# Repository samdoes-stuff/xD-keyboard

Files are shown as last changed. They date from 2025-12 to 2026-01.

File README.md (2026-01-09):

# xD-keyboard
xD keyboard is nRF52 based wireless mechanical keyboard equipped with Gateron KS-33 low profile key switches. 

# PCB 

Generated with KLEPCBGEN. Designed with both Kicad & Easyeda PRO.

Screenshot 2026-01-08 231322 - Copy













# Case & Plate 

Generated with Swillkb & Keebio. Designed with Fusion 360. Chopped with Bamboo lab Studio.





Counter sink screw holes







# Bootloader & Firmware

Bootloader generated from Adafruit_nRF52_Bootloader & Firmware made with ZMK with Custom Board.
- ZMK Ultra-Low-Power Mode
- Deep sleep between keypresses
- BLE connection optimization
- Soft-off / idle timeout
- ZMK USB HID (wired mode)

#BOM 

Refer to BOM.csv

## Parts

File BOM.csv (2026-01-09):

Index | LCSC# | MPN | Manufacturer | Package |  |  | Quantity | MOQ | Unit Price($) | Extended Price($) | Product Link
1 | C23733 | CL05A475MP5NRNC | Samsung Electro-Mechanics | 402 |  |  | 50 | 50 | 0.0049 | 0.25 | https://www.lcsc.com/product-detail/C23733.html
2 | C52923 | CL05A105KA5NQNC | Samsung Electro-Mechanics | 402 |  |  | 100 | 100 | 0.003 | 0.3 | https://www.lcsc.com/product-detail/C52923.html
3 | C272875 | CC0402KRX7R9BB473 | YAGEO | 402 |  |  | 100 | 100 | 0.0024 | 0.24 | https://www.lcsc.com/product-detail/C272875.html
4 | C1523 | 0402B102K500NT | FH | 402 |  |  | 100 | 100 | 0.0011 | 0.11 | https://www.lcsc.com/product-detail/C1523.html
5 | C1546 | 0402CG101J500NT | FH | 402 |  |  | 100 | 100 | 0.001 | 0.1 | https://www.lcsc.com/product-detail/C1546.html
6 | C307331 | CL05B104KB54PNC | Samsung Electro-Mechanics | 402 |  |  | 100 | 100 | 0.0038 | 0.38 | https://www.lcsc.com/product-detail/C307331.html
7 | C1548 | 0402CG150J500NT | FH | 402 |  |  | 100 | 100 | 0.001 | 0.1 | https://www.lcsc.com/product-detail/C1548.html
8 | C1552 | 0402CG1R5C500NT | FH | 402 |  |  | 100 | 100 | 0.0012 | 0.12 | https://www.lcsc.com/product-detail/C1552.html
9 | C1550 | 0402CG1R0C500NT | FH | 402 |  |  | 100 | 100 | 0.0012 | 0.12 | https://www.lcsc.com/product-detail/C1550.html
10 | C15195 | CL05B103KB5NNNC | Samsung Electro-Mechanics | 402 |  |  | 100 | 100 | 0.0013 | 0.13 | https://www.lcsc.com/product-detail/C15195.html
11 | C72038 | 19-213/Y2C-CQ2R2L/3T(CY) | EVERLIGHT | 603 |  |  | 30 | 30 | 0.0208 | 0.62 | https://www.lcsc.com/product-detail/C72038.html
12 | C8598 | B5819W SL | JSCJ | SOD-123 |  |  | 20 | 20 | 0.023 | 0.46 | https://www.lcsc.com/product-detail/C8598.html
13 | C2290 | KT-0603W | Hubei KENTO Elec | 603 |  |  | 50 | 50 | 0.0106 | 0.53 | https://www.lcsc.com/product-detail/C2290.html
14 | C7420320 | 1N4148WT | R+O | SOD-523 |  |  | 100 | 50 | 0.0111 | 1.11 | https://www.lcsc.com/product-detail/C7420320.html
15 | C76763 | MLG1005S15NJT000 | TDK | 402 |  |  | 10 | 10 | 0.0064 | 0.06 | https://www.lcsc.com/product-detail/C76763.html
16 | C76732 | MLF1608E100KTD00 | TDK | 603 |  |  | 10 | 10 | 0.0417 | 0.42 | https://www.lcsc.com/product-detail/C76732.html
17 | C76775 | MLG1005S3N9BT000 | TDK | 402 |  |  | 10 | 10 | 0.0083 | 0.08 | https://www.lcsc.com/product-detail/C76775.html
18 | C165948 | TYPE-C-31-M-12 | Korean Hroparts Elec | SMD |  |  | 5 | 5 | 0.1762 | 0.88 | https://www.lcsc.com/product-detail/C165948.html
19 | C17168 | 0402WGF0000TCE | UNI-ROYAL | 402 |  |  | 100 | 100 | 0.0006 | 0.06 | https://www.lcsc.com/product-detail/C17168.html
20 | C25744 | 0402WGF1002TCE | UNI-ROYAL | 402 |  |  | 100 | 100 | 0.0006 | 0.06 | https://www.lcsc.com/product-detail/C25744.html
21 | C13167 | 0603WAF2701T5E | UNI-ROYAL | 603 |  |  | 100 | 100 | 0.0012 | 0.12 | https://www.lcsc.com/product-detail/C13167.html
22 | C25867 | 0402WGF1501TCE | UNI-ROYAL | 402 |  |  | 100 | 100 | 0.0006 | 0.06 | https://www.lcsc.com/product-detail/C25867.html
23 | C25905 | 0402WGF5101TCE | UNI-ROYAL | 402 |  |  | 100 | 100 | 0.0006 | 0.06 | https://www.lcsc.com/product-detail/C25905.html
24 | C22976 | 0603WAF2004T5E | UNI-ROYAL | 603 |  |  | 100 | 100 | 0.0013 | 0.13 | https://www.lcsc.com/product-detail/C22976.html
25 | C26082 | 0402WGF1005TCE | UNI-ROYAL | 402 |  |  | 100 | 100 | 0.0006 | 0.06 | https://www.lcsc.com/product-detail/C26082.html
26 | C26083 | 0402WGF1004TCE | UNI-ROYAL | 402 |  |  | 100 | 100 | 0.0006 | 0.06 | https://www.lcsc.com/product-detail/C26083.html
27 | C318884 | TS-1187A-B-A-B | XKB Connection | SMD-4P,5.1x5.1mm |  |  | 20 | 20 | 0.0195 | 0.39 | https://www.lcsc.com/product-detail/C318884.html
28 | C202311 | BQ21040DBVR | TI | SOT-23-6 |  |  | 5 | 5 | 0.2758 | 1.38 | https://www.lcsc.com/product-detail/C202311.html
29 | C190794 | NRF52840-QIAA-R | NORDIC | AQFN-73-EP(7x7) |  |  | 1 | 1 | 4.5064 | 4.51 | https://www.lcsc.com/product-detail/C190794.html
30 | C94372 | ESDR0502NMUTAG | onsemi | UDFN-6(1x1.2) |  |  | 5 | 5 | 0.2563 | 1.28 | https://www.lcsc.com/product-detail/C94372.html
31 | C99009 | X1A0000610006 | EPSON | SMD2012-2P |  |  | 5 | 5 | 0.2058 | 1.03 | https://www.lcsc.com/product-detail/C99009.html
32 | C2965584 | XL7EL89COI-111YLC-32M | YXC Crystal Oscillators | SMD2016-4P |  |  | 10 | 10 | 0.0747 | 0.75 | https://www.lcsc.com/product-detail/C2965584.html
33 |  | Raspberry pi pico or xiao rp2040 for booting the MCU |  |  |  |  | 1 | 1 | 0 | 0 | I have ONE
34 | C42393296 |  | Single Conductor HookUp Wire |  |  |  | 4 | 50 | $0.01 | $0.48 | https://www.lcsc.com/product-detail/C42393296.html
35 |  | Gateron Low Profile Switch (Brown) |  |  |  |  | 60 | 70 | 21.65 | 21.65 | https://www.aliexpress.com/item/1005006870413847.html?mp=1
36 |  | Low Profile Keycaps |  |  |  |  | 60 | 60 | 17.81 | 17.81 | https://www.aliexpress.com/item/1005007750036083.html?mp=1
37 |  | Hot Swap Sockets |  |  |  |  | 60 | 70 | 8.53 | 8.53 | https://www.aliexpress.com/item/1005007267551458.html?mp=1
38 |  | Low Profile Stabilizer Set |  |  |  |  | set of 5 | set of 5 | 11.59 | 11.59 | https://www.aliexpress.com/item/1005005296240590.html?mp=1
39 |  | Keyboard PCB (ENIG for nRF52 bga) |  |  |  |  |  |  | 58.6 | 58.6
40 |  | JLCPCB SHIPPING |  |  |  |  |  |  | 14.85 | 14.85
41 |  | LCSC SHIPPING |  | SINGAPORE POST |  |  |  |  | 13.29 | 13.29
42 |  | ALIEXPRESS SHIPPING |  |  |  |  |  |  | FREE | Banger
43 |  | Top Plate 1.2mm with dummy 8.8block which I will later sand in |  |  |  |  |  |  | Printing Legion
44 |  | BACK CASE |  |  | (PRINTING LEGION) |  | (BRO ALLOT ME SOME .PEOPLE NEED SHIPPING CHARGE TO SEND TO MY PLACE. WE HAVE NONE)
45 |  | Phillips 5mm Flat headed M2 screws x4 |  |  |  |  |  |  | 0 | 0 | I have enough
46 |  | 160 mAH 20x20x4 mm 3.7V battery |  |  |  |  |  |  | 0 | 0 | I have One
 |  |  |  |  |  | Total |  |  |  | 162.76

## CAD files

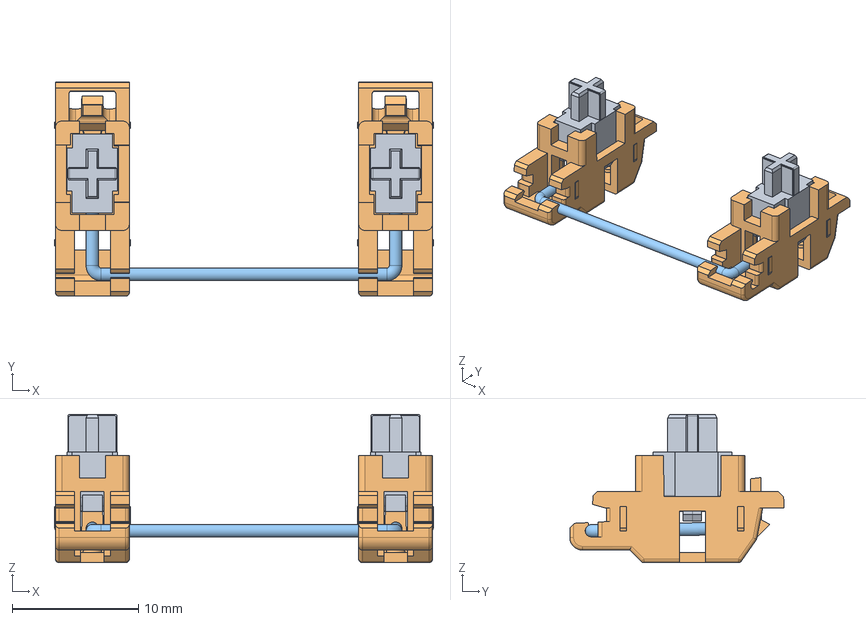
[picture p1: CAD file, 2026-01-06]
3D/LP_Stabilizer.stp
30.0 x 17.0 x 11.8 mm

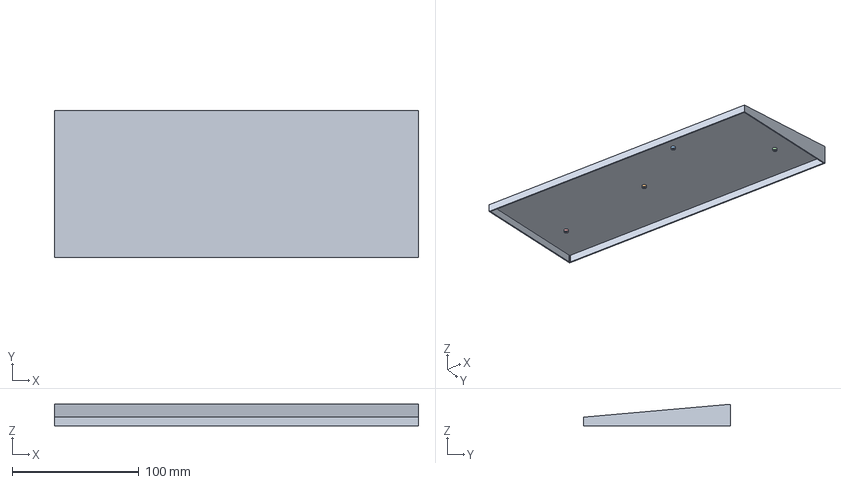
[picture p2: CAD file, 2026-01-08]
Plates/BackPlate.step
287.4 x 116.0 x 17.0 mm

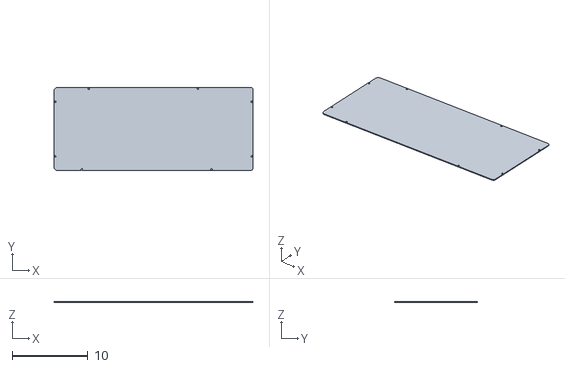
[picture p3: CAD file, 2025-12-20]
Reboot Keyboard/3D Files/Final BackPlate.stl
26.3 x 11.0 x 0.1

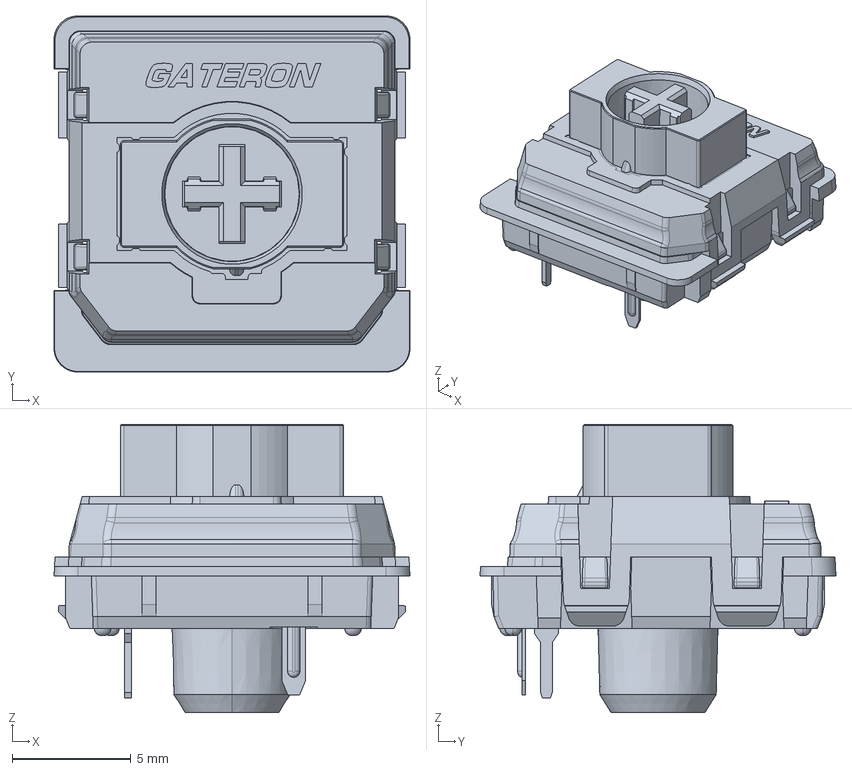
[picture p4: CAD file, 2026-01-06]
3D/KS-33_LP_SWITCH.stp
15.0 x 15.0 x 12.1 mm

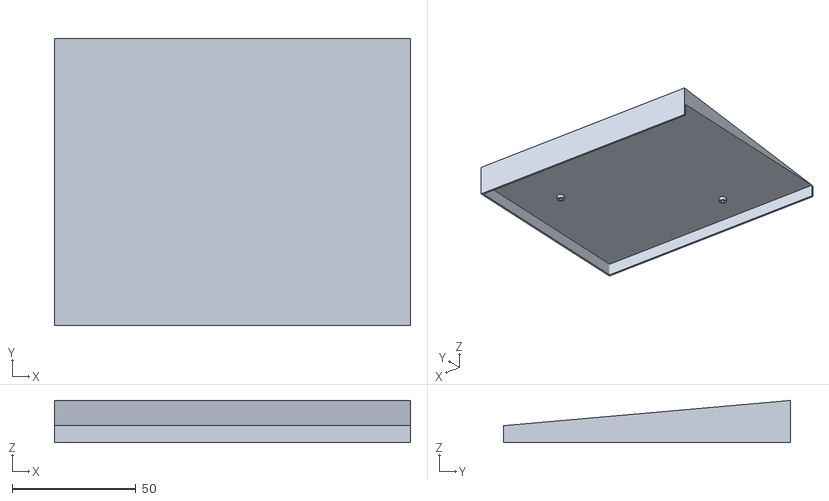
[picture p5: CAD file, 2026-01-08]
Plates/BackPlate.step_A.stl
143.7 x 116.0 x 17.0

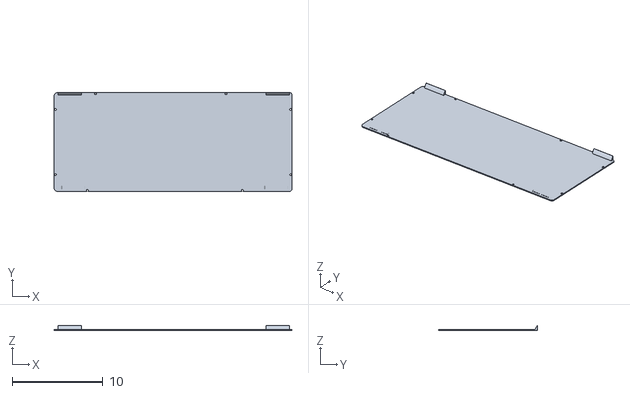
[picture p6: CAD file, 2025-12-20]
Reboot Keyboard/3D Files/BackPlate.stl
26.3 x 11.0 x 0.582

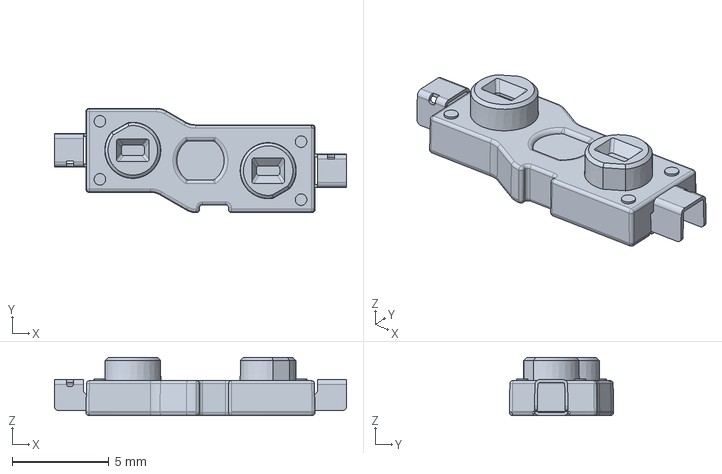
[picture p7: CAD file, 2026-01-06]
3D/hotswap_socket.stp
15.1 x 5.39 x 3.00 mm

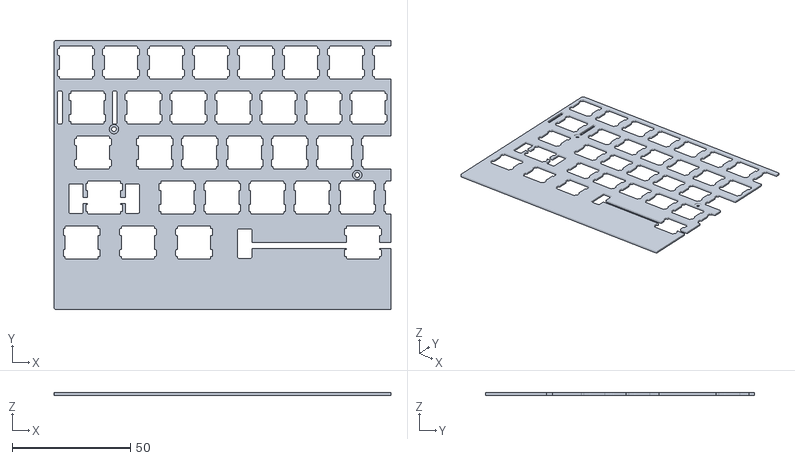
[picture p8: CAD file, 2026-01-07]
Plates/mykbplate.step_B.stl
142.7 x 114.0 x 1.20

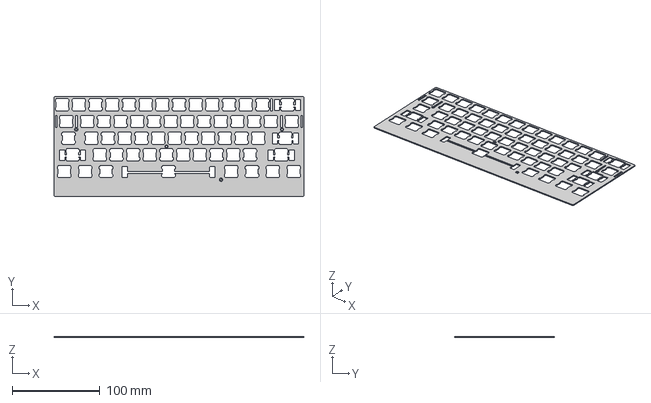
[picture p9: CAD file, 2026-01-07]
Plates/mykbplate.step
285.4 x 114.0 x 1.20 mm

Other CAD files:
Plates/BackPlate.step_B.stl
Plates/mykbplate.step_A.stl
Plates/mykbplate.3mf
Plates/mykbplate.dxf
Reboot Keyboard/3D Files/#911-003-Keycap-Caps-Lock.f3d
Reboot Keyboard/3D Files/#911-004-Keycap-SpaceBar.f3d
Reboot Keyboard/3D Files/#911-006-Keycap-Operator.f3d
Reboot Keyboard/3D Files/Untitled.f3d

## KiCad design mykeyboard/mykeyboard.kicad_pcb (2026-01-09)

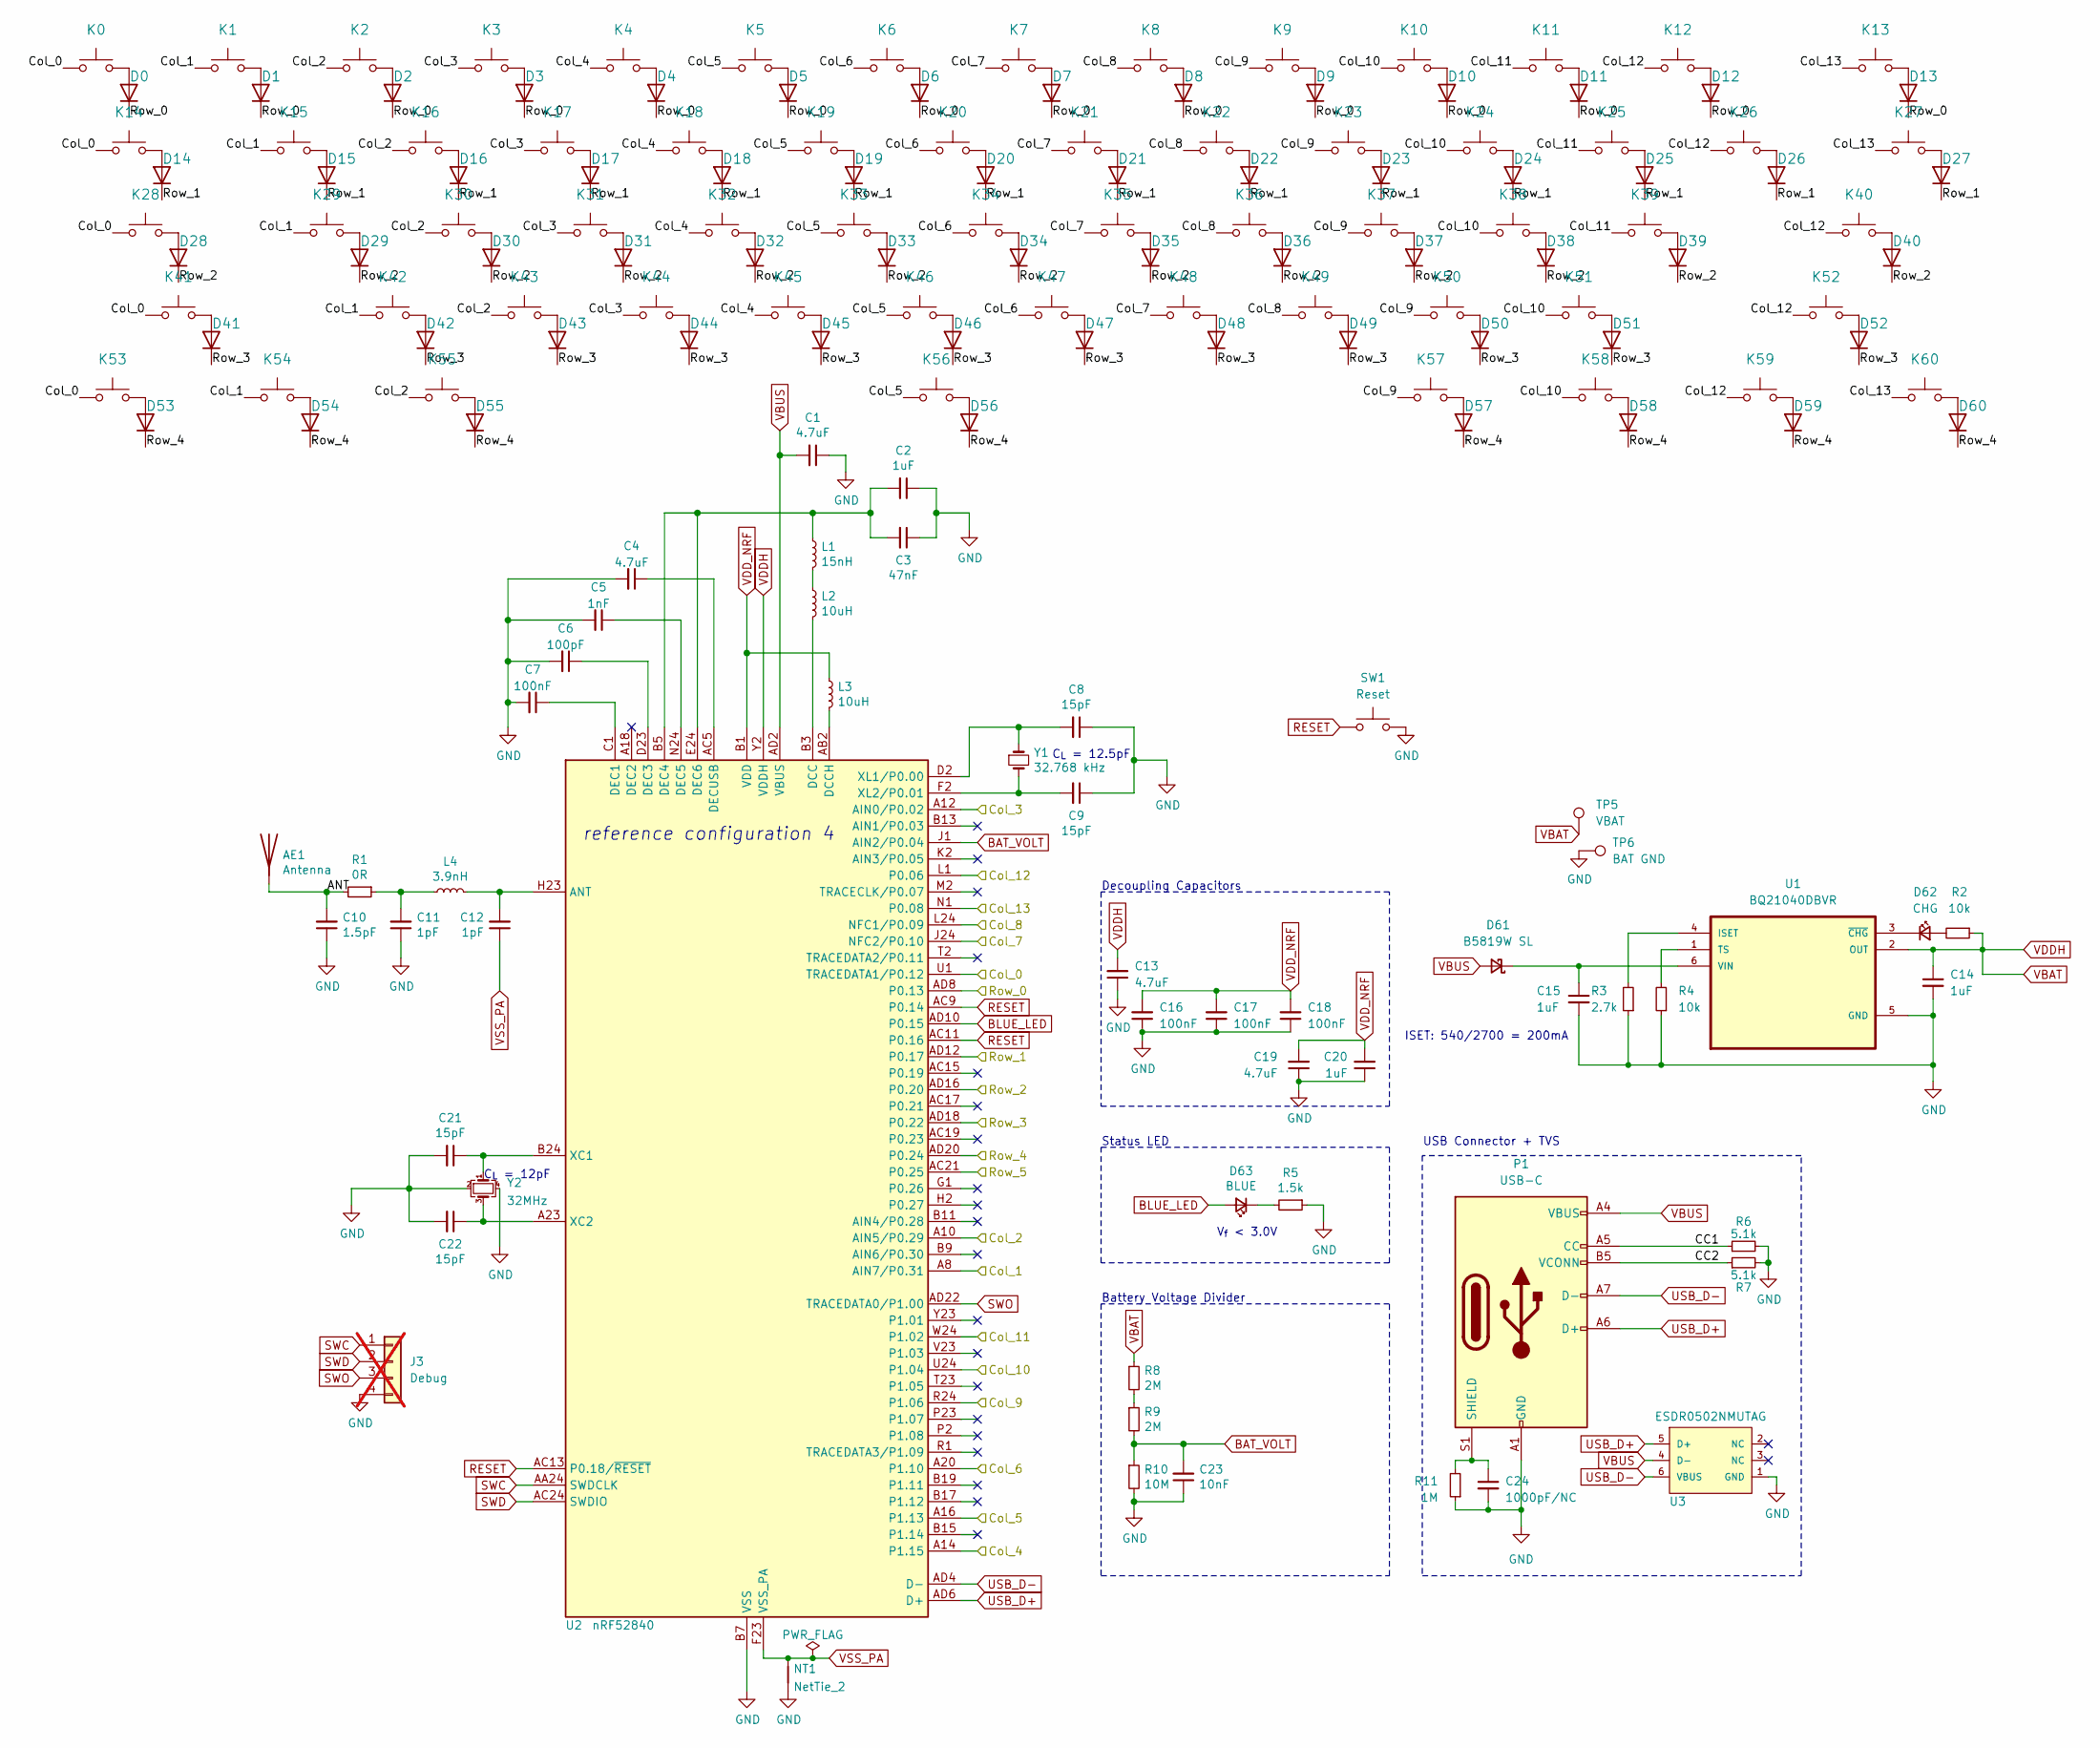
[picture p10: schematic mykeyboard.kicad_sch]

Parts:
AE1: Antenna; 2.4GHz-meander-antenna-v2
C1, C4, C13, C19: 4.7uF; C_0402_1005Metric; Manufacturer Part CL05A475KP5NRNC; LCSC C23733
C2, C14, C15, C20: 1uF; C_0402_1005Metric; Manufacturer Part CL05A105KO5NNNC; LCSC C52923
C3: 47nF; C_0402_1005Metric; Manufacturer Part CL05B473KO5NNNC; LCSC C272875
C5: 1nF; C_0402_1005Metric; Manufacturer Part CL05B102KB5NNNC; LCSC C1523
C6: 100pF; C_0402_1005Metric; Manufacturer Part CL05C101JB5NNNC; LCSC C1546
C7, C16, C17, C18: 100nF; C_0402_1005Metric; Manufacturer Part CL05B104KA5NNNC; LCSC C307331
C8, C9, C21, C22: 15pF; C_0402_1005Metric; Manufacturer Part CL05C150JB51PNC; LCSC C1548
C10: 1.5pF; C_0402_1005Metric; Manufacturer Part CL05C1R5CB5NNNC; LCSC C1552
C11, C12: 1pF; C_0402_1005Metric; Manufacturer Part CL05C010CB5NNNC; LCSC C1550
C23: 10nF; C_0402_1005Metric; Manufacturer Part CL05B103KB5NNNC; LCSC C15195
C24: 1000pF/NC; C_0402_1005Metric
D0, D1, D2, D3, D4, D5, D6, D7, D8, D9, D10, D11, D12, D13, D14, D15, D16, D17, D18, D19, D20, D21, D22, D23, D24, D25, D26, D27, D28, D29, D30, D31, D32, D33, D34, D35, D36, D37, D38, D39, D40, D41, D42, D43, D44, D45, D46, D47, D48, D49, D50, D51, D52, D53, D54, D55, D56, D57, D58, D59, D60: D; D_SOD-523
D61: B5819W SL; D_SOD-323; Manufacturer Part PMEG4010CEJ; LCSC C8598
D62: CHG; LED_0603_1608Metric; Manufacturer Part 19-217/S2C-AQ1R1B/3T; LCSC C72038
D63: BLUE; LED_0603_1608Metric; Manufacturer Part 19-217/BHC-ZL1M2RY/3T; LCSC C2290
J3: Debug; PinHeader_1x04_P2.54mm_Vertical; not fitted
K0: ~~,`; Gateron-KS33-Hotswap-1U
K1: !,1; Gateron-KS33-Hotswap-1U
K2: @,2; Gateron-KS33-Hotswap-1U
K3: #,3; Gateron-KS33-Hotswap-1U
K4: $,4; Gateron-KS33-Hotswap-1U
K5: %,5; Gateron-KS33-Hotswap-1U
K6: ^,6; Gateron-KS33-Hotswap-1U
K7: &,7; Gateron-KS33-Hotswap-1U
K8: *,8; Gateron-KS33-Hotswap-1U
K9: (,9; Gateron-KS33-Hotswap-1U
K10: ),0; Gateron-KS33-Hotswap-1U
K11: _,-; Gateron-KS33-Hotswap-1U
K12: +,=; Gateron-KS33-Hotswap-1U
K13: Backspace; Gateron-KS33-Hotswap-2U
K14: Tab; Gateron-KS33-Hotswap-1.5U
K15: Q; Gateron-KS33-Hotswap-1U
K16: W; Gateron-KS33-Hotswap-1U
K17: E; Gateron-KS33-Hotswap-1U
K18: R; Gateron-KS33-Hotswap-1U
K19: T; Gateron-KS33-Hotswap-1U
K20: Y; Gateron-KS33-Hotswap-1U
K21: U; Gateron-KS33-Hotswap-1U
K22: I; Gateron-KS33-Hotswap-1U
K23: O; Gateron-KS33-Hotswap-1U
K24: P; Gateron-KS33-Hotswap-1U
K25: {,[; Gateron-KS33-Hotswap-1U
K26: },]; Gateron-KS33-Hotswap-1U
K27: |,\; Gateron-KS33-Hotswap-1.5U
K28: Caps Lock; Gateron-KS33-Hotswap-1.75U
K29: A; Gateron-KS33-Hotswap-1U
K30: S; Gateron-KS33-Hotswap-1U
K31: D; Gateron-KS33-Hotswap-1U
K32: F; Gateron-KS33-Hotswap-1U
K33: G; Gateron-KS33-Hotswap-1U
K34: H; Gateron-KS33-Hotswap-1U
K35: J; Gateron-KS33-Hotswap-1U
K36: K; Gateron-KS33-Hotswap-1U
K37: L; Gateron-KS33-Hotswap-1U
K38: :,;; Gateron-KS33-Hotswap-1U
K39: ",'; Gateron-KS33-Hotswap-1U
K40: Enter; Gateron-KS33-Hotswap-2.25U
K41: Shift; Gateron-KS33-Hotswap-2.25U
K42: Z; Gateron-KS33-Hotswap-1U
K43: X; Gateron-KS33-Hotswap-1U
K44: C; Gateron-KS33-Hotswap-1U
K45: V; Gateron-KS33-Hotswap-1U
K46: B; Gateron-KS33-Hotswap-1U
K47: N; Gateron-KS33-Hotswap-1U
K48: M; Gateron-KS33-Hotswap-1U
K49: <,,; Gateron-KS33-Hotswap-1U
K50: >,.; Gateron-KS33-Hotswap-1U
K51: ?,/; Gateron-KS33-Hotswap-1U
K52: Shift; Gateron-KS33-Hotswap-2.75U
K53, K60: Ctrl; Gateron-KS33-Hotswap-1.25U
K54, K58: Win; Gateron-KS33-Hotswap-1.25U
K55, K57: Alt; Gateron-KS33-Hotswap-1.25U
K56: Blank; Gateron-KS33-Hotswap-6.25U
K59: Menu; Gateron-KS33-Hotswap-1.25U
L1: 15nH; L_0402_1005Metric; Manufacturer Part MLG1005S15NJT000; LCSC C27143
L2, L3: 10uH; L_0603_1608Metric; Manufacturer Part MLF1608E100KTD00; LCSC C285968
L4: 3.9nH; L_0402_1005Metric; Manufacturer Part MLG1005S3N9BT000; LCSC C14033
NT1: NetTie_2; net-tie-2-tiny
P1: USB-C; USB_C_Receptacle_HRO_TYPE-C-31-M-12; LCSC C165948
R1: 0R; R_0402_1005Metric; Manufacturer Part RC0402FR-070RL; LCSC C17168
R2, R4: 10k; R_0402_1005Metric; Manufacturer Part RC0402FR-0710KL; LCSC C25744
R3: 2.7k; R_0603_1608Metric; Manufacturer Part RC0402FR-0710KL; LCSC C13167
R5: 1.5k; R_0402_1005Metric; Manufacturer Part RC0402FR-071K5L; LCSC C25867
R6, R7: 5.1k; R_0402_1005Metric; Manufacturer Part RC0402FR-075K1L; LCSC C25905
R8, R9: 2M; R_0603_1608Metric; Manufacturer Part RC0402FR-072ML; LCSC C22976
R10: 10M; R_0402_1005Metric; Manufacturer Part RC0402FR-0710ML; LCSC C26082
R11: 1M; R_0402_1005Metric; LCSC C26083
SW1: Reset; SW_Push_1P1T_XKB_TS-1187A; LCSC C318884
TP5: VBAT; TestPoint_Pad_2.5x2.5mm
TP6: BAT GND; TestPoint_Pad_2.5x2.5mm
U1: BQ21040DBVR; SOT95P280X145-6N; LCSC C202311
U2: nRF52840; Nordic_AQFN-73-1EP_7x7mm_P0.5mm; Manufacturer Part NRF52840-QIAA-R; LCSC C190794
U3: ESDR0502NMUTAG; UDFN-6_1.2x1.0mm_P0.4mm; Manufacturer Part ESDR0502NMUTBG; LCSC C327480
Y1: 32.768 kHz; Crystal_SMD_2012-2Pin_2.0x1.2mm; Manufacturer Part SC20S-12.5PF20PPM; LCSC C99009
Y2: 32MHz; Crystal_SMD_2016-4Pin_2.0x1.6mm; Manufacturer Part Q22FA1280001800; LCSC C2965584

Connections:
/ANT: AE1.1 (A), C10.2, R1.2
/CC1: P1.A5 (CC), R6.1
/CC2: P1.B5 (VCONN), R7.1
/Col_0: K0.1, K14.1, K28.1, K41.1, K53.1, U2.U1 (TRACEDATA1/P0.12)
/Col_1: K1.1, K15.1, K29.1, K42.1, K54.1, U2.A8 (AIN7/P0.31)
/Col_2: K2.1, K16.1, K30.1, K43.1, K55.1, U2.A10 (AIN5/P0.29)
/Col_3: K3.1, K17.1, K31.1, K44.1, U2.A12 (AIN0/P0.02)
/Col_4: K4.1, K18.1, K32.1, K45.1, U2.A14 (P1.15)
/Col_5: K5.1, K19.1, K33.1, K46.1, K56.1, U2.A16 (P1.13)
/Col_6: K6.1, K20.1, K34.1, K47.1, U2.A20 (P1.10)
/Col_7: K7.1, K21.1, K35.1, K48.1, U2.J24 (NFC2/P0.10)
/Col_8: K8.1, K22.1, K36.1, K49.1, U2.L24 (NFC1/P0.09)
/Col_9: K9.1, K23.1, K37.1, K50.1, K57.1, U2.R24 (P1.06)
/Col_10: K10.1, K24.1, K38.1, K51.1, K58.1, U2.U24 (P1.04)
/Col_11: K11.1, K25.1, K39.1, U2.W24 (P1.02)
/Col_12: K12.1, K26.1, K40.1, K52.1, K59.1, U2.L1 (P0.06)
/Col_13: K13.1, K27.1, K60.1, U2.N1 (P0.08)
/Row_0: D0.1 (K), D1.1 (K), D2.1 (K), D3.1 (K), D4.1 (K), D5.1 (K), D6.1 (K), D7.1 (K), D8.1 (K), D9.1 (K), D10.1 (K), D11.1 (K), D12.1 (K), D13.1 (K), U2.AD8 (P0.13)
/Row_1: D14.1 (K), D15.1 (K), D16.1 (K), D17.1 (K), D18.1 (K), D19.1 (K), D20.1 (K), D21.1 (K), D22.1 (K), D23.1 (K), D24.1 (K), D25.1 (K), D26.1 (K), D27.1 (K), U2.AD12 (P0.17)
/Row_2: D28.1 (K), D29.1 (K), D30.1 (K), D31.1 (K), D32.1 (K), D33.1 (K), D34.1 (K), D35.1 (K), D36.1 (K), D37.1 (K), D38.1 (K), D39.1 (K), D40.1 (K), U2.AD16 (P0.20)
/Row_3: D41.1 (K), D42.1 (K), D43.1 (K), D44.1 (K), D45.1 (K), D46.1 (K), D47.1 (K), D48.1 (K), D49.1 (K), D50.1 (K), D51.1 (K), D52.1 (K), U2.AD18 (P0.22)
/Row_4: D53.1 (K), D54.1 (K), D55.1 (K), D56.1 (K), D57.1 (K), D58.1 (K), D59.1 (K), D60.1 (K), U2.AD20 (P0.24)
BAT_VOLT: C23.2, R9.2, R10.1, U2.J1 (AIN2/P0.04)
BLUE_LED: D63.2 (A), U2.AD10 (P0.15)
unnamed: C11.2, L4.1, R1.1
unnamed: D0.2 (A), K0.2
unnamed: D1.2 (A), K1.2
unnamed: D2.2 (A), K2.2
unnamed: D3.2 (A), K3.2
unnamed: D4.2 (A), K4.2
unnamed: D5.2 (A), K5.2
unnamed: D6.2 (A), K6.2
unnamed: D7.2 (A), K7.2
unnamed: D8.2 (A), K8.2
unnamed: D9.2 (A), K9.2
unnamed: D10.2 (A), K10.2
unnamed: D11.2 (A), K11.2
unnamed: D12.2 (A), K12.2
unnamed: D13.2 (A), K13.2
unnamed: D14.2 (A), K14.2
unnamed: D15.2 (A), K15.2
unnamed: D16.2 (A), K16.2
unnamed: D17.2 (A), K17.2
unnamed: D18.2 (A), K18.2
unnamed: D19.2 (A), K19.2
unnamed: D20.2 (A), K20.2
unnamed: D21.2 (A), K21.2
unnamed: D22.2 (A), K22.2
unnamed: D23.2 (A), K23.2
unnamed: D24.2 (A), K24.2
unnamed: D25.2 (A), K25.2
unnamed: D26.2 (A), K26.2
unnamed: D27.2 (A), K27.2
unnamed: D28.2 (A), K28.2
unnamed: D29.2 (A), K29.2
unnamed: D30.2 (A), K30.2
unnamed: D31.2 (A), K31.2
unnamed: D32.2 (A), K32.2
unnamed: D33.2 (A), K33.2
unnamed: D34.2 (A), K34.2
unnamed: D35.2 (A), K35.2
unnamed: D36.2 (A), K36.2
unnamed: D37.2 (A), K37.2
unnamed: D38.2 (A), K38.2
unnamed: D39.2 (A), K39.2
unnamed: D40.2 (A), K40.2
unnamed: D41.2 (A), K41.2
unnamed: D42.2 (A), K42.2
unnamed: D43.2 (A), K43.2
unnamed: D44.2 (A), K44.2
unnamed: D45.2 (A), K45.2
unnamed: D46.2 (A), K46.2
unnamed: D47.2 (A), K47.2
unnamed: D48.2 (A), K48.2
unnamed: D49.2 (A), K49.2
unnamed: D50.2 (A), K50.2
unnamed: D51.2 (A), K51.2
unnamed: D52.2 (A), K52.2
unnamed: D53.2 (A), K53.2
unnamed: D54.2 (A), K54.2
unnamed: D55.2 (A), K55.2
unnamed: D56.2 (A), K56.2
unnamed: D57.2 (A), K57.2
unnamed: D58.2 (A), K58.2
unnamed: D59.2 (A), K59.2
unnamed: D60.2 (A), K60.2
unnamed: C15.1, D61.1 (K), U1.6 (VIN)
unnamed: D62.2 (A), R2.2
unnamed: D62.1 (K), U1.3 (~CHG)
unnamed: D63.1 (K), R5.2
unnamed: L1.2, L2.1
unnamed: C24.1, P1.S1 (SHIELD), R11.2
unnamed: R8.2, R9.1
unnamed: R3.2, U1.4 (ISET)
unnamed: R4.2, U1.1 (TS)
unnamed: C12.2, L4.2, U2.H23 (ANT)
unnamed: L2.2, U2.B3 (DCC)
unnamed: L3.2, U2.AB2 (DCCH)
unnamed: C7.1, U2.C1 (DEC1)
unnamed: C6.1, U2.D23 (DEC3)
unnamed: C2.2, C3.2, L1.1, U2.B5 (DEC4), U2.E24 (DEC6)
unnamed: C5.1, U2.N24 (DEC5)
unnamed: C4.1, U2.AC5 (DECUSB)
unnamed: C21.1, U2.B24 (XC1), Y2.1
unnamed: C22.1, U2.A23 (XC2), Y2.3
unnamed: C8.2, U2.D2 (XL1/P0.00), Y1.1
unnamed: C9.2, U2.F2 (XL2/P0.01), Y1.2
RESET: SW1.1, U2.AC9 (P0.14), U2.AC11 (P0.16), U2.AC13 (P0.18/~RESET)
USB_D+: P1.A6 (D+), P1.B6 (D+), U2.AD6 (D+), U3.5 (D+)
USB_D-: P1.A7 (D-), P1.B7 (D-), U2.AD4 (D-), U3.6 (VBUS)
VBAT: C13.2, C14.1, R2.1, R8.1, TP5.1, U1.2 (OUT), U2.Y2 (VDDH)
VBUS: C1.2, D61.2 (A), P1.A4 (VBUS), P1.A9 (VBUS), P1.B4 (VBUS), P1.B9 (VBUS), U2.AD2 (VBUS), U3.4 (D-)
VDD_NRF: C16.2, C17.2, C18.2, C19.2, C20.2, L3.1, U2.A22 (VDD), U2.AD14 (VDD), U2.AD23 (VDD), U2.B1 (VDD), U2.W1 (VDD)
VSS_PA: C12.1, NT1.1, U2.F23 (VSS_PA)

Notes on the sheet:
C_{L} = 12pF
Battery Voltage Divider
V_{f} < 3.0V
Decoupling Capacitors
ISET: 540/2700 = 200mA
reference configuration 4
Status LED
USB Connector + TVS
C_{L} = 12.5pF

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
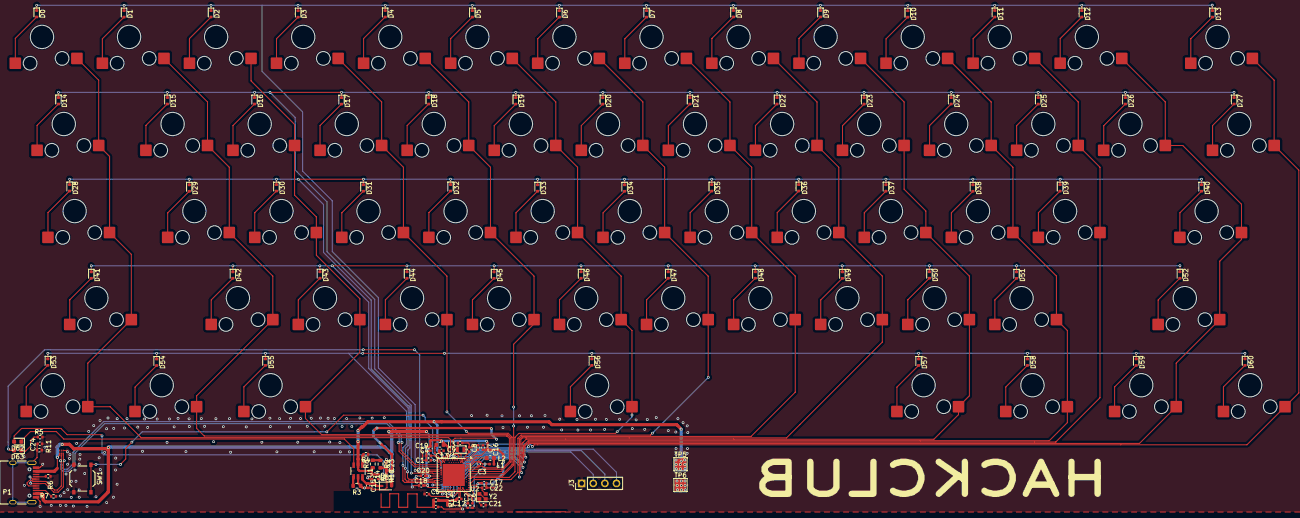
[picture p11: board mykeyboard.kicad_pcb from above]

Board: 2 copper layers, 176 parts (0 on the bottom side), 118 nets.

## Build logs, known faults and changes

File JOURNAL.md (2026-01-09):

## Go to https://blueprint.hackclub.com/projects/1992

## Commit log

2026-01-06 PUSH MY BOY
    [BOM.csv, BackPlate.step, KS-33_LP_SWITCH.stp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]
2026-01-07 Plate Me
    [BackPlate.step, BackPlate.step_A.stl, BackPlate.step_B.stl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]
2026-01-08 Thas how cooking work
    [BackPlate.step, BackPlate.step_A.stl, BackPlate.step_B.stl]
2026-01-08 Found cheaper things
    [BOM.csv]
2026-01-09 ITSY CHANGE
    [mykbplate.3mf, mykeyboard.kicad_pcb]
2026-01-09 Stabilizer Cost add
    [BOM.csv]
2026-01-09 Enhance README with additional project details
    Expanded the README with detailed sections on PCB, case, bootloader, and BOM.
